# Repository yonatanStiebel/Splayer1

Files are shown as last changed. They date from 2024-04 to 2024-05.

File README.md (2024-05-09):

# Splayer1

<br>
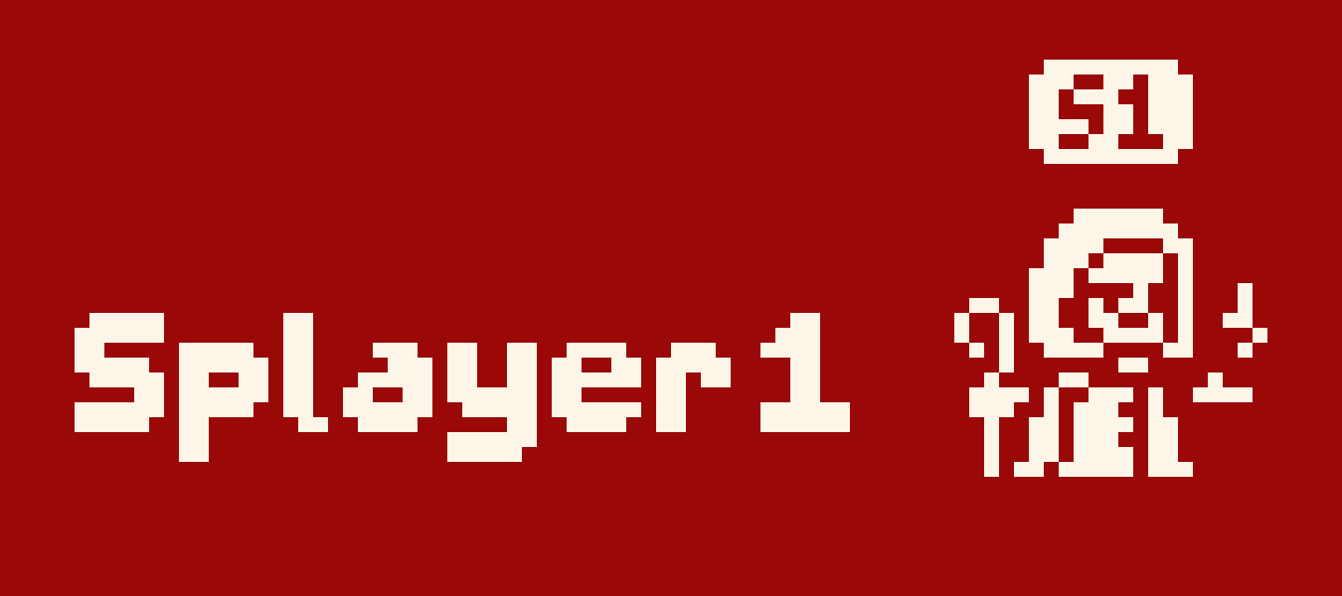
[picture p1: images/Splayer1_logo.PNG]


**Splayer1** is a split, wireless, ortholinear, column-staggered, splayed keyboard.

<br>
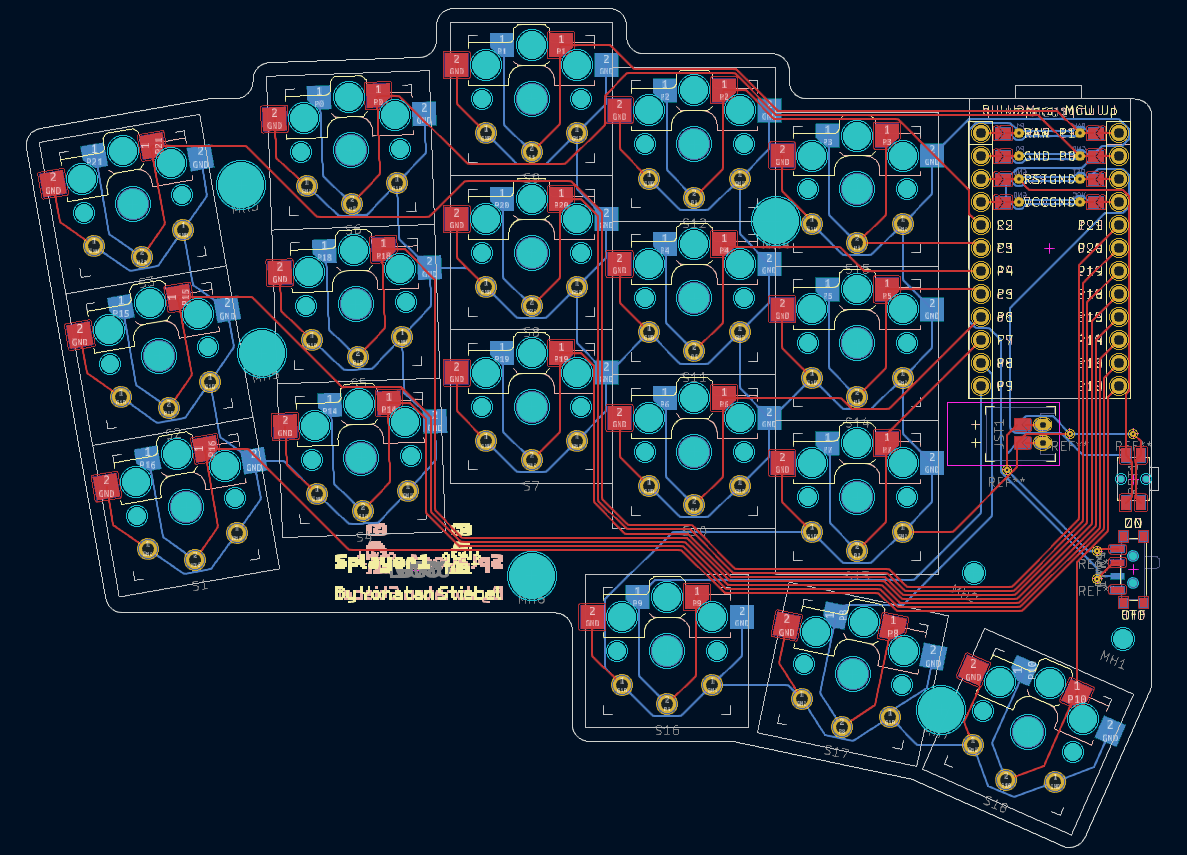
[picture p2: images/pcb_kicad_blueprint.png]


Each half of the keyboard has 3 rows, 5 columns and 3 extra thumb keys. 

The pinky and ring finger columns are slightly staggered and splayed (hence the name), making for a non-aggressive layout.

The board is choc-spaced, compatible with V1 Kailh Choc switches. 

The keyboard is diodeless and hotswappable, so it can be assembled with minimal solder work. 

The PCB is flippable, and meant to be used for both halves of the keyboard.

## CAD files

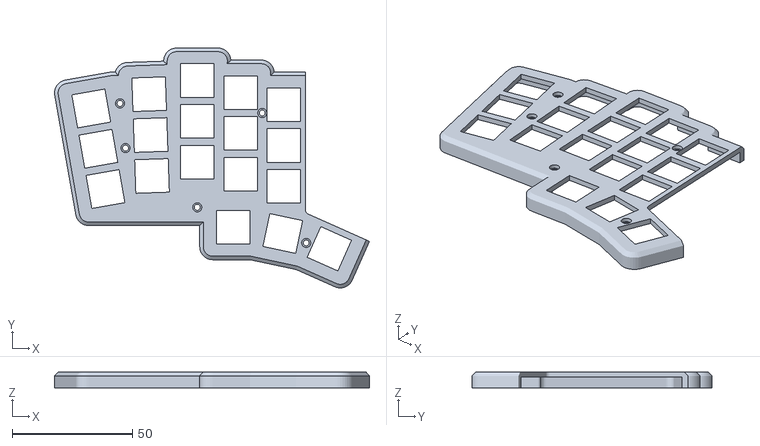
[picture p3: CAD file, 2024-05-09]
case/top left of case.stl
130.9 x 99.7 x 6.50

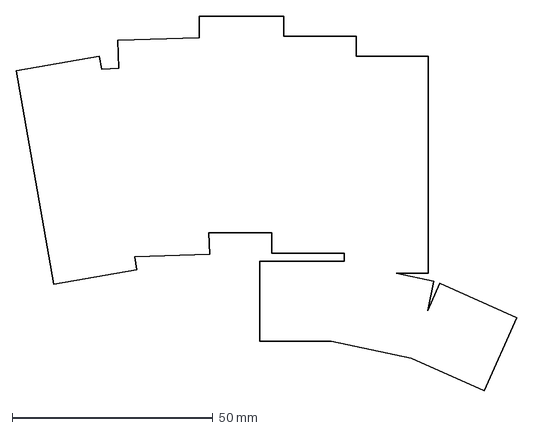
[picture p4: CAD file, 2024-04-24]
output/outlines/keys_outline.dxf
124.7 x 93.3 mm

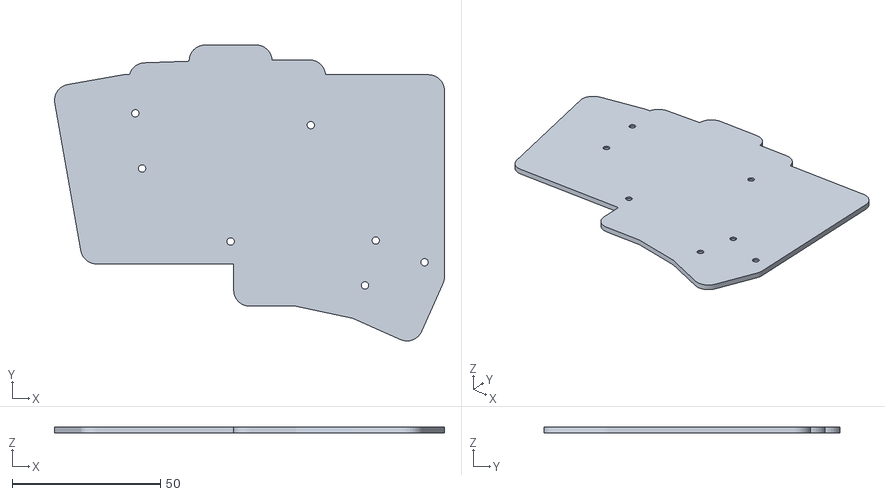
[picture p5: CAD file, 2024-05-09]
case/bottom left of case.stl
131.4 x 99.7 x 2.00

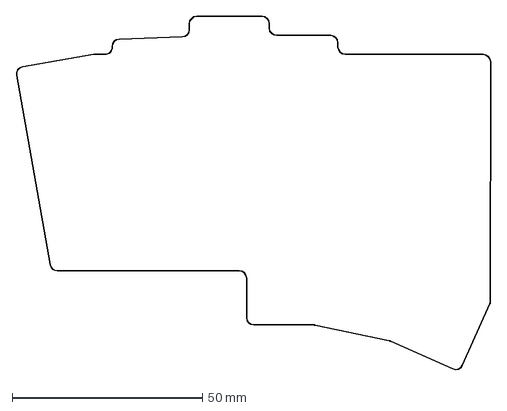
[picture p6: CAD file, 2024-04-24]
output/outlines/board.dxf
124.5 x 93.0 mm

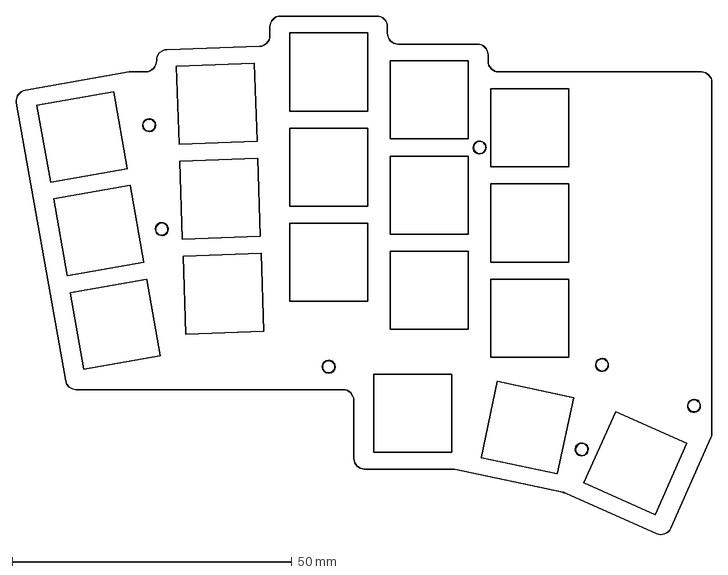
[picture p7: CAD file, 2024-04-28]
output/pcbs/case_blueprint-brd.dxf
124.5 x 92.8 mm

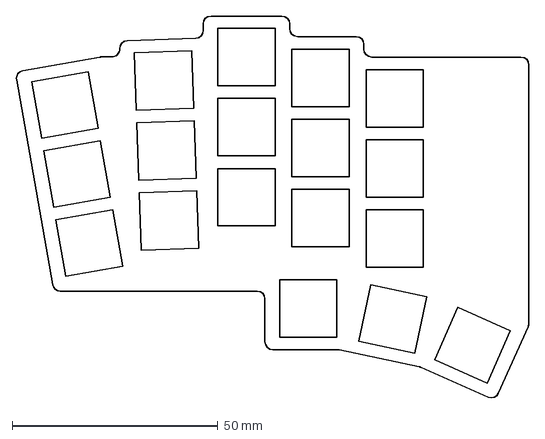
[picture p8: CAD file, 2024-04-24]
output/outlines/case_top_plate.dxf
124.5 x 93.0 mm

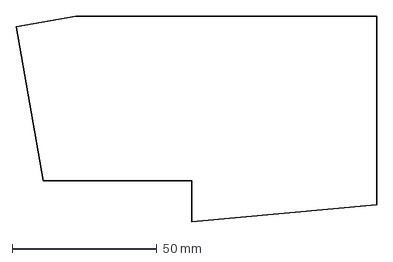
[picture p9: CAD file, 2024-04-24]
output/outlines/polygon.dxf
124.7 x 71.1 mm

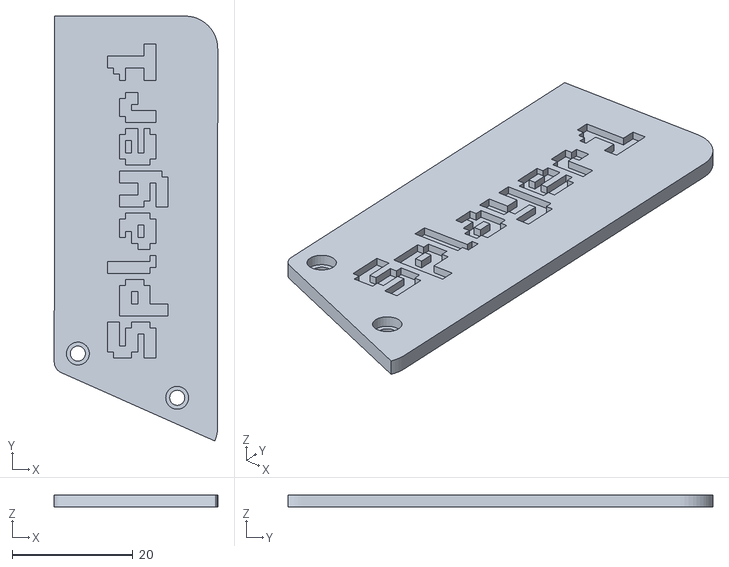
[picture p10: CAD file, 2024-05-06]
case/Left MCU cover v1.stl
27.1 x 70.4 x 2.00

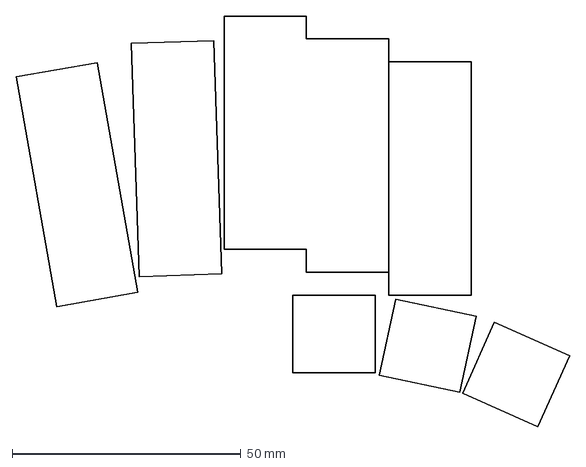
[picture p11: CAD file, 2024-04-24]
output/outlines/keys.dxf
121.0 x 89.8 mm

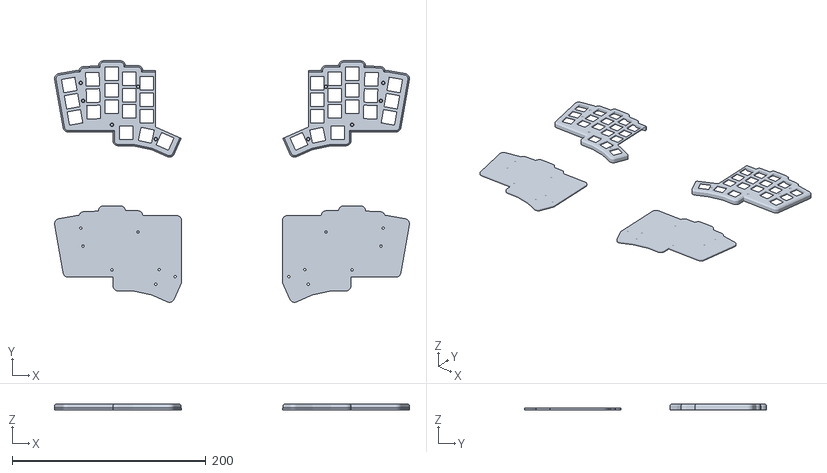
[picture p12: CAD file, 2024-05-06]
case/walled 2mm case.stl
366.8 x 249.7 x 6.50

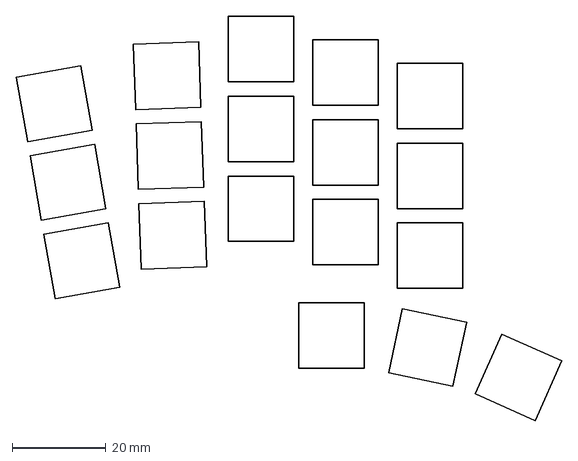
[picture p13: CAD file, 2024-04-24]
output/outlines/switch_hole.dxf
116.2 x 86.1 mm

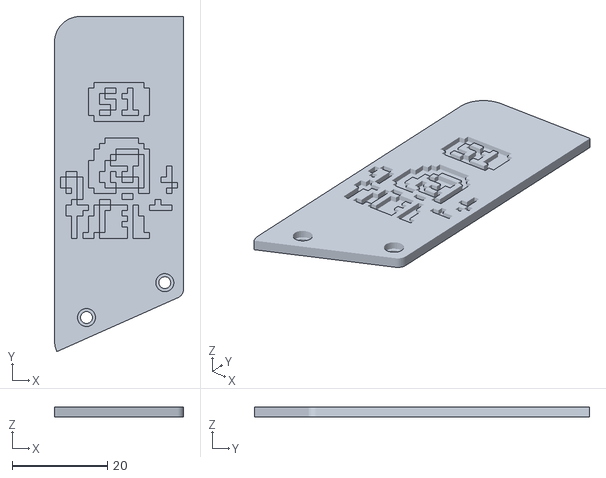
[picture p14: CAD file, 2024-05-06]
case/Right MCU cover v1.stl
27.1 x 70.4 x 2.00

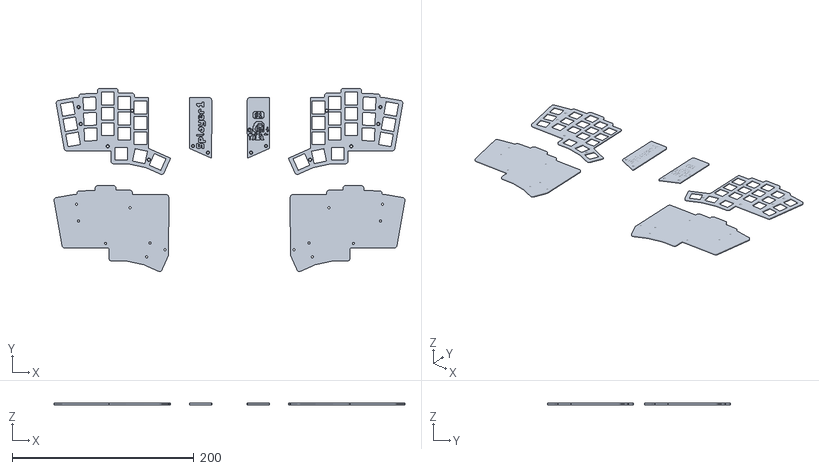
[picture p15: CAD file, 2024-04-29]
case/Splayer1 plate case correct orientation.stl
386.6 x 201.6 x 1.80

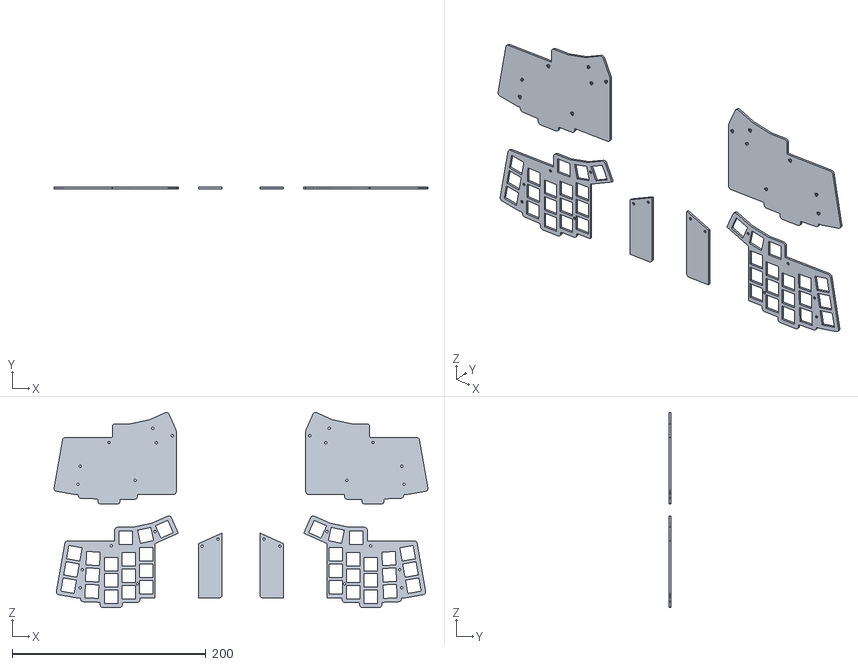
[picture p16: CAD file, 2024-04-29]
case/Splayer1 plate case 2mm.stl
386.6 x 2.00 x 201.6

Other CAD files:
output/pcbs/Splayer 1 logo.dxf
case/top right of case.stl
case/bottom right of case.stl
case/Final 2mm Splayer1 plate case_.stl
case/Splayer1 Case v3.stl
case/Splayer1 plate case v1.stl

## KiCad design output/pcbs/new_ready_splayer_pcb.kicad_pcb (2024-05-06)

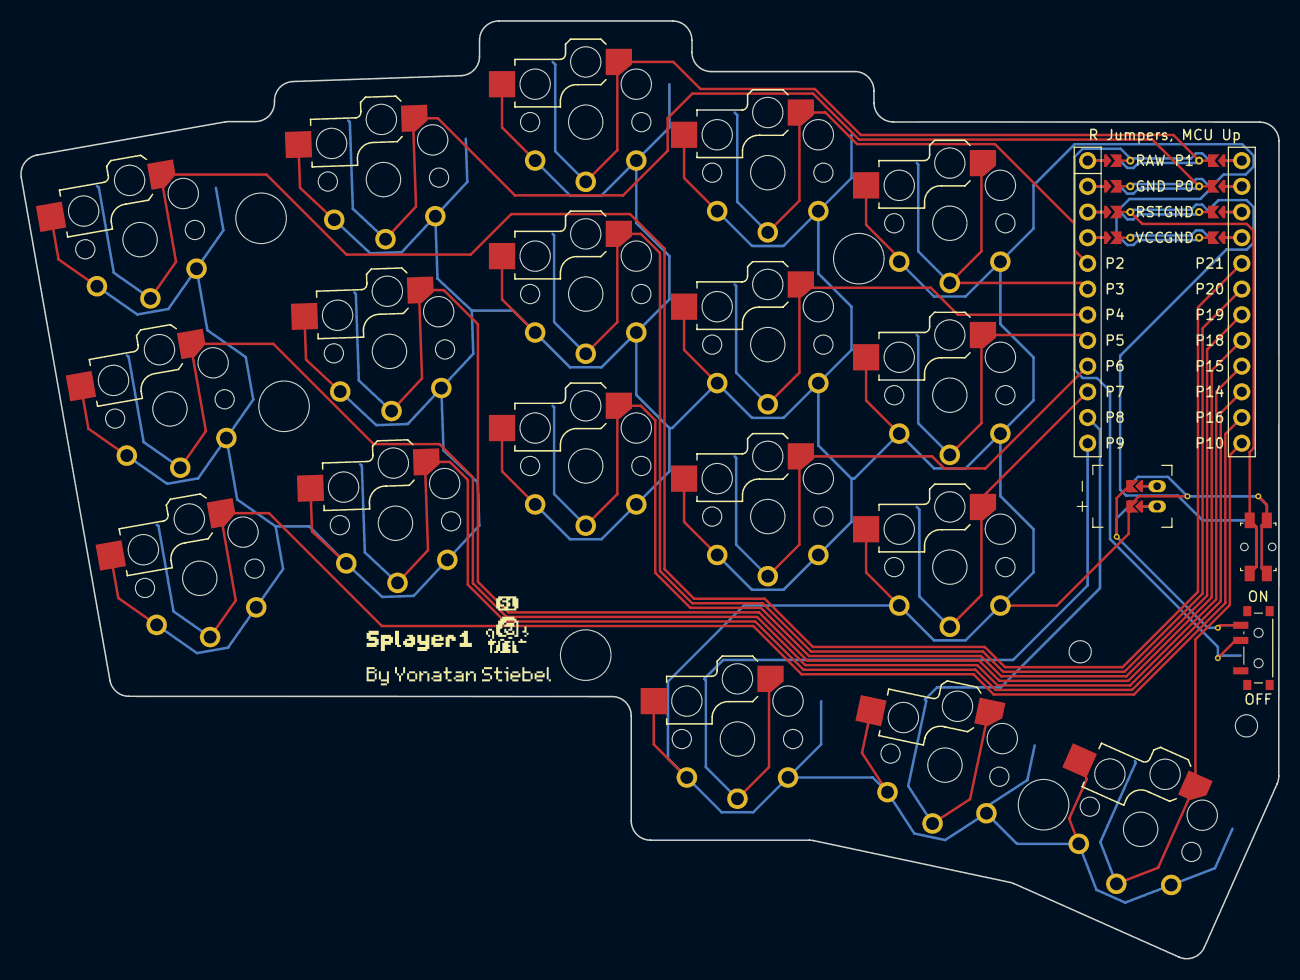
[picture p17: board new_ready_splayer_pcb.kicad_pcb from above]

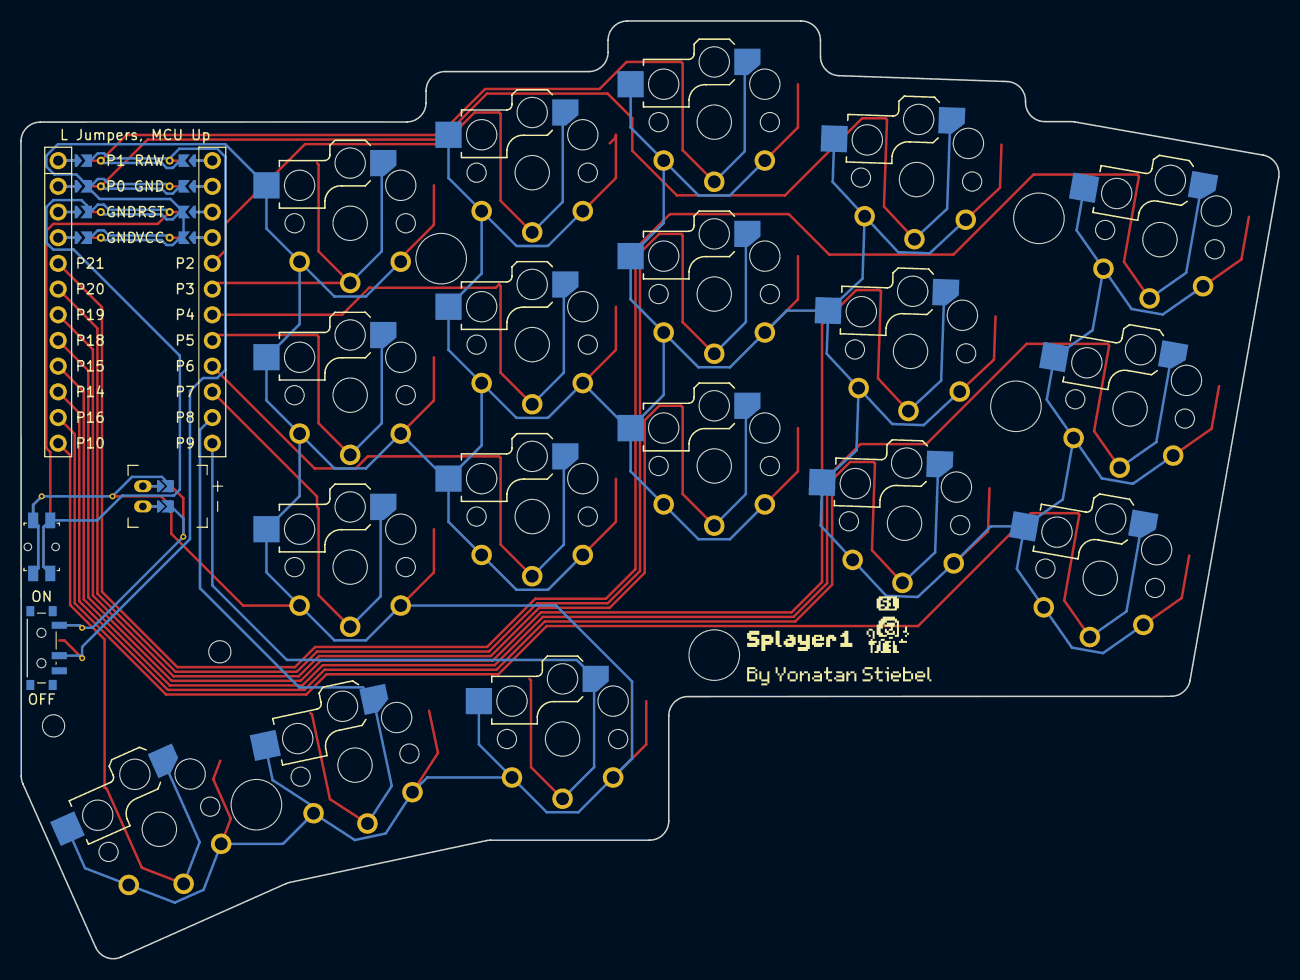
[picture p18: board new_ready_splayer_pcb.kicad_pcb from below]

Board: 2 copper layers, 124.4 x 92.7 mm, 29 parts (18 on the bottom side), 24 nets.

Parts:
JST1: battery_connector_jst_ph_2
MCU1: mcu_nice_nano
MH1, MH2, MH3, MH4, MH5, MH6, MH7: mounting_hole_npth
PWR1: power_switch_smd_side
RST1: reset_button_smd_side
S1, S2, S3, S4, S5, S6, S7, S8, S9, S10, S11, S12, S13, S14, S15, S16, S17, S18: switch_choc_v1_v2

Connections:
BAT_P: JST1.1, PWR1.1, PWR1.3
GND: JST1.2, MCU1.3, MCU1.4, MCU1.123, RST1.1, RST1.3, S1.1, S1.2, S2.1, S2.2, S3.1, S3.2, S4.1, S4.2, S5.1, S5.2, S6.1, S6.2, S7.1, S7.2, S8.1, S8.2, S9.1, S9.2, S10.1, S10.2, S11.1, S11.2, S12.1, S12.2, S13.1, S13.2, S14.1, S14.2, S15.1, S15.2, S16.1, S16.2, S17.1, S17.2, S18.1, S18.2
JST1_1: JST1.11, JST1.21, JST1.31
JST1_2: JST1.12, JST1.22, JST1.32
P0: MCU1.2, S6.1, S6.2
P1: MCU1.1, S9.1, S9.2
P2: MCU1.20, S12.1, S12.2
P3: MCU1.19, S15.1, S15.2
P4: MCU1.18, S11.1, S11.2
P5: MCU1.17, S14.1, S14.2
P6: MCU1.16, S10.1, S10.2
P7: MCU1.15, S13.1, S13.2
P8: MCU1.14, S17.1, S17.2
P9: MCU1.13, S16.1, S16.2
P10: MCU1.12, S18.1, S18.2
P14: MCU1.10, S4.1, S4.2
P15: MCU1.9, S2.1, S2.2
P16: MCU1.11, S1.1, S1.2
P18: MCU1.8, S5.1, S5.2
P19: MCU1.7, S7.1, S7.2
P20: MCU1.6, S8.1, S8.2
P21: MCU1.5, S3.1, S3.2
RAW: MCU1.124, PWR1.2
RST: MCU1.122, RST1.2, RST1.4

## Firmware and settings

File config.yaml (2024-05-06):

metadata:
  engine: 4.1.0
  template: kicad8
  keyboard: Splayer 1
  version: 1.0
  author: Yoragon

units:
  # Proxy spacing variables
  kx: cx
  ky: cy
  # Padding variables
  px: kx + 3
  py: ky + 3
  # Adjusting preview to choc keys
  $default_width: cx
  $default_height: cy

  # Stagger values used in the matrix
  ring_stagger: 2
  matrix_stagger: 5

  # Splay values used in the matrix
  pinky_splay: 10
  ring_splay: -8
  nullify_splay: -(ring_splay+pinky_splay)
  thumb_splay: -12

  # Spread values used in the matrix
  pinky_ring_spread: kx+2
  ring_middle_stagger: kx+1

  # Shift value of the controller
  controller_shift_x: kx+3.25
  controller_shift_y: 10.491
  # Shift value of the battery plug
  battery_shift_x: kx+2.5
  battery_shift_y: -10
  # Shift value of the reset button
  reset_shift_x: kx+12.5
  reset_shift_y: -15
  # Shift value of the slider switch
  slider_shift_x: kx+12.5
  slider_shift_y: -25

points:
  key:
    # Choc spacing
    padding: ky
    spread: kx

  zones:
    # Primary 3x5 key matrix
    matrix:
      # Fix placement on KiCAD sheet.
      anchor:
        shift: [100, -100]
      columns:
        pinky:
          key:
            bind: 0
            splay: pinky_splay
          rows:
              top:
#                column_net: P2
                column_net: P21
              home:
#                column_net: P6
                column_net: P15
              bottom:
#                column_net: P8
                column_net: P16

        ring:
          key:
            splay: ring_splay
            spread: pinky_ring_spread
            stagger: ring_stagger
          rows:
            top:
              column_net: P0
            home:
#              column_net: P5
              column_net: P18
            bottom:
#              column_net: P7
              column_net: P14

        middle:
          key:
            stagger: matrix_stagger
            splay: nullify_splay
            spread: ring_middle_stagger
          rows:
            top:
              column_net: P1
            home:
#              column_net: P3
              column_net: P20
            bottom:
#              column_net: P4
              column_net: P19

        index:
          key:
            stagger: -matrix_stagger
          rows:
            top:
#              column_net: P21
              column_net: P2
            home:
#              column_net: P19
              column_net: P4
            bottom:
#              column_net: P15
              column_net: P6

        inner:
          key:
            stagger: -matrix_stagger
          rows:
            top:
#              column_net: P20
              column_net: P3
            home:
#              column_net: P18
              column_net: P5
            bottom:
#              column_net: P14
              column_net: P7

      rows:
        bottom:
        home:
        top:

    # Thumb cluster keys
    thumbs:
      # The thumb cluster is anchored to the bottom left, though it is shifted such that the middle key of the cluster is placed under the inner column of the main matrix
      anchor:
        ref: matrix_inner_bottom
        shift: [-kx-3,-ky]

      columns:
        outer:
          key:
#            column_net: P10
            column_net: P9

        main:
          key:
            bind: [0,0,0,3]
            splay: thumb_splay
            shift: [3,-2]
#            column_net: P16
            column_net: P8

        inner:
          key:
            splay: thumb_splay
            shift: [6,-3]
#            column_net: P9
            column_net: P10

outlines:
  keys_outline:
    - what: rectangle
      where: true
      size: [px, py]
      bound: true

  keys:
    - what: rectangle
      where: true
      size: [kx, ky]

  switch_hole:
    - what: rectangle
      where: true
      size: [13.95, 13.95]

  polygon:
    - what: polygon
      operation: stack
      points:
        - ref: matrix_pinky_top
          shift: [-0.5px,0.5py]
        - ref: matrix_pinky_top
          shift: [0.5px,0.5py]
        - ref: matrix_inner_top
          shift: [1.55px,0.5py]
        - ref: thumbs_inner
          shift: [0.5px,0.5py]
        - ref: thumbs_outer
          shift: [-0.5px,-0.5py]
        - ref: thumbs_outer
          shift: [-0.5px,0.21py]
        - ref: matrix_pinky_bottom
          shift: [-0.5px,-0.5py]

  board:
    - name: keys_outline
    - operation: add
      name: polygon
      fillet: 1.9

  case_top_plate:
    - name: board
    - operation: subtract
      name: switch_hole
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

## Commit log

2024-04-24 tryoing to commit files
    [Splayer1 Case v3.stl, board.dxf, case_blueprint-brd.dxf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]
2024-04-25 updated footprints to ceoloide footprints
    [case_blueprint.kicad_pcb, splayer_pcb.kicad_pcb]
2024-04-25 switched to ceoloide mounting hole frootprints, and designated a folder for ceoloide footprints to be consistent with the website. flushed the MCU against the inner wall of the case
    [splayer_pcb.kicad_pcb]
2024-04-27 redefined mounting holes positions
    [case_blueprint.kicad_pcb, splayer_pcb.kicad_pcb]
2024-04-27 added routed pcb
    [ready_splayer_pcb.kicad_pcb, splayer_sketch.kicad_pcb]
2024-04-28 designed a new plate case for the keyboard
    [Splayer 1 logo.dxf, Splayer1 plate case v1.stl, case_blueprint-brd.dxf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]
2024-04-29 added gerber folder and the final case stl file
    [Final 2mm Splayer1 plate case_.stl, Splayer1 plate case 2mm.stl, Splayer1 plate case correct orientation.stl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]
2024-05-06 redesigned the PCB to avoid errors, removed choc v2 support
    [Left MCU cover v1.stl, Right MCU cover v1.stl, case_blueprint.kicad_pcb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]
2024-05-06 drilled holes for reset side buttons
    [new_ready_splayer_pcb-B_Cu.gbr, new_ready_splayer_pcb-B_Mask.gbr, new_ready_splayer_pcb-B_Paste.gbr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]
2024-05-09 added seperate stl fiiles for the case
    [bottom left of case.stl, bottom right of case.stl, top left of case.stl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]
